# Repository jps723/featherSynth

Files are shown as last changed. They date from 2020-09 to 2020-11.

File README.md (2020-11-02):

# Feather Synth Build Notes 9/4/20

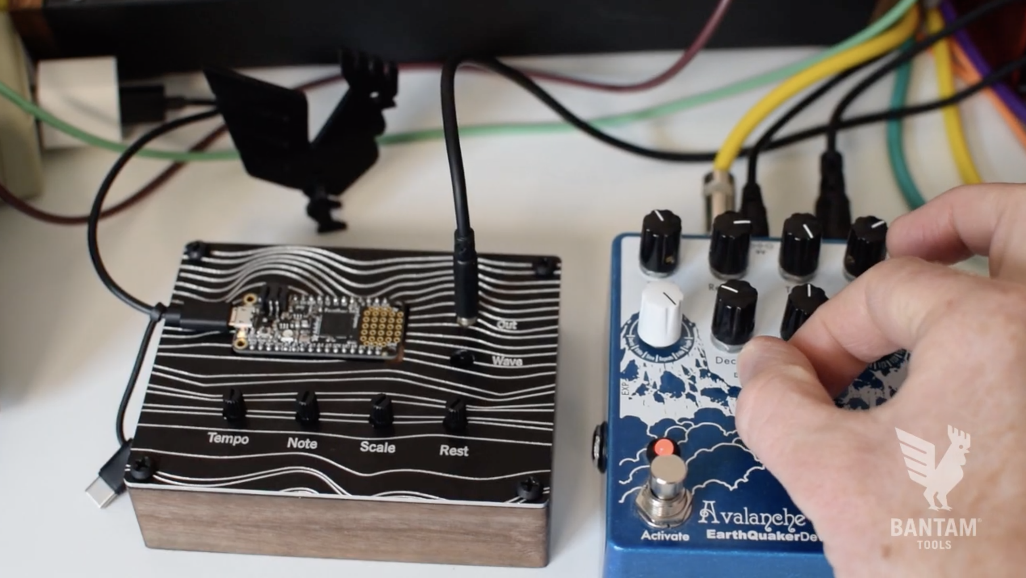
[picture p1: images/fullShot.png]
The Feather Synth sits on top of a table next to a guitar pedal. A hand is adjusting a knob on the pedal


A dual-oscillator polyphonic synthesizer project in collaboration with [Bantam Tools](https://www.bantamtools.com/).  The [project build](https://www.hackster.io/news/create-a-synth-and-sequencer-using-bantam-tools-desktop-cnc-milling-machine-83a0fdb942a3) guide is available on Hackster.

**Design Notes:**

The hardware component of this project is centered around the Adafruit Feather M4 Express.  This board has two 12bit DAC pins allowing for stereo audio synthesis, however this project does not use any stereo effects and delivers a mono signal to a 3.5mm mono audio jack.  

The hardware design has 5 inputs in the form of 4 potentiometers and a tactile button.  There are exposed female headers for an Adafruit Feather M4 Express.  The board will only fit in one direction, with the microUSB port facing to the left.  

If you look at the [pinout](https://learn.adafruit.com/adafruit-feather-m4-express-atsamd51/pinouts) of the M4 Express, you’ll see that we are using analog pin A0 as our DAC/audio output, and A2-A5 as our analog inputs.  Our button connects to digital pin 5.

The base software for the device uses these inputs to control an auto-advancing sequence of notes.  The knobs control the root note, the scale (it comes pre-programmed with the 7 diatonic modes), the probability that the note will play, and the time delay between notes/tempo.  Pressing the button will cycle through different waveforms/oscillator types.

**Synthesizer Design**
The synth is a polyphonic dual-oscillator synthesizer, each with independent bi-quad filters and envelopes.  The envelope settings are static while the filters are set to Low Pass Filters with the frequency cutoff randomly changing between two static values based on probability (math within the software -- this is unrelated to the probability knob).   

**Controls**
Root Note (Tonic)
The note from which the scale begins.  By default the notes to choose from range from A0 to C8

**Scale Selector**
There are a total of seven scales to choose from, beginning with the major scale, and then each mode variant resulting in the 7 diatonic modes in western music.

**Probability**
The probability that the note will be played, as calculated by comparing the knob’s position to a randomly generated number. Ex. 0-100% chance of playing

**Tempo**
The overall tempo of the sequence as determined by delay between each note

**Waveform Selector**
This is a series of oscillator combinations that get cycled through using the button.

## **Code**
The code is broken up into two separate files:  

**featherSynth.ino**
This is our primary code and is broken up into two sections: setup and loop.  Setup runs once, while loop cycles through continuously after the setup code has been executed. All of the code above the setup() function is required to call the library we are using (Audio.h), call our reference file (scales.h), and initialize our global variables. All of the code below the main loop() are functions that are called from either within setup() or loop().

Setup() contains code for setting audio memory allocation, pin assignment, and a function called oscillatorSetup() that is used for setting initial values of our oscillators/envelopes, etc.  These will mostly get overwritten by the loop however we want to define our instrument before the program begins to cycle.  

loop() contains the bulk of our code. We have a function called buttonHandler() that is used for managing what we want to happen when we press the button. If you find this function below, you can add further oscillator combinations.  Our potentiometer readings are assigned to the Feather pins here as well. If you want to change the order of the knobs, do it here.

The nested for() loop is used to populate the rootScaled array.  This determines what notes are in the sequence and the order that they’re arranged in.  There are two arrangements to choose from, either climbing the scale, or random selection.  Only one can be used at a time.

The frequency is calculated using a formula that stems from midi note values which are a standard form of notation for relating to frequency.

The frequency cutoff is currently assigned a 50% chance of being 7000 hz, or 2000 hz.  Experiment with these numbers.

The probabilityOfPlaying variable is compared to a random value between 0 and 100.  Since probabilityOfPlaying is also a value between 0 and 100, this is treated as a percentage.  You can experiment with these values.

playOsc1() and playOsc2() functions take one argument (frequency) which is calculated via the explanation above.  These functions also contain the methods for dictating the ADSR envelope values which are hardcoded and can be adjusted and should be experimented with.  The filter frequency cutoff and delayTime are also embedded in these functions, with delayTime being used to set the time between notes (our tempo).

The buttonHandler function counts the button presses and uses that count to cycle through the 7 different oscillator combinations in the switch statement.

scales.h
scales.h is a reference file where we have all of our different scales stored.  The base code has 7 scales (each of the diatonic modes) spread out across two octaves, with the root note at each octave playing at a 3:1 ratio to everything else.  This results in an 18 note array (an array with 18 indices), which are all a part of another array that contains each of these arrays (a total of 7).  If you were to add an 8th scale with 18 notes, then the scales[][] array should be initialized as scales[8][18].  This would also need to be changed in the .ino sketch in the rootScaled[][] array.  

Currently, if the knob is turned all the way to the left, the Ionian (major) Scale is selected.  As the knob is turned to the right, each scale from the array is played in the order that they are presented in the scales.h file.

## Build Process

**TOP**
Bit: 1/64”
Mill Time: ~3mins

**BOTTOM**
Bit: 1/32”, 1/64”
Mill Time: ~11mins

It’s easiest to solder in this order:
```
1. Vias
2. Resistor
3. Headers
4. Audio jack
5. Tactile button
6. Pots
```

Test

First follow [this guide](https://learn.adafruit.com/adafruit-feather-m4-express-atsamd51) for getting acquainted with the board and setting up your arduino IDE to use it. For the SAMD Board Support (Adafruit version), version 1.5.14 is verified to work.  Version 1.6+ has introduced a problem that will break the code without generating any errors.

Additionally, you will need to install the Adafruit fork of the PJRC Audio Library via the IDE.  



And also the following libraries:

```
Adafruit_SPIFlash
Adafruit_Zero_I2S_Library
SDFat-Adafruit Fork
```

Once all of the dependencies have been installed, and you’ve uploaded a trial sketch, upload the code that you’ve downloaded from the repository and have fun!  

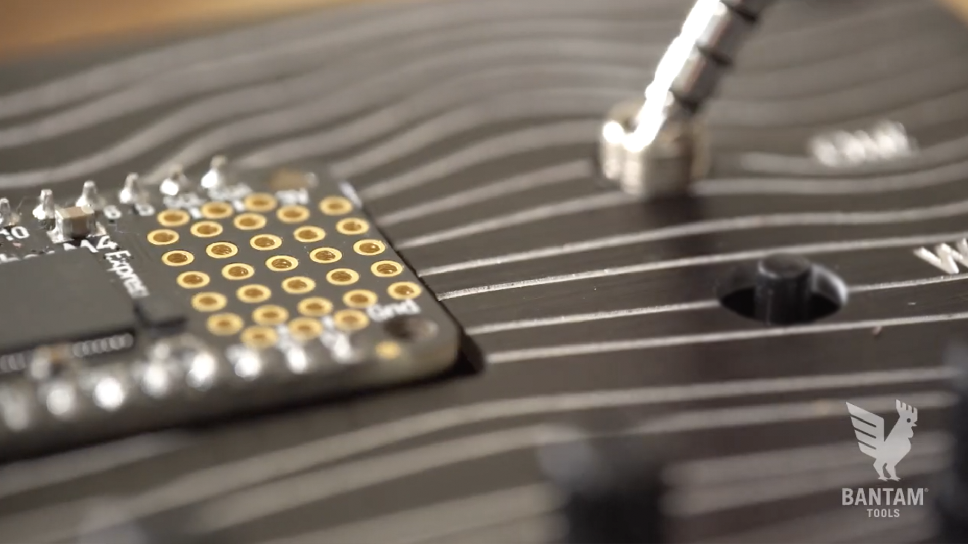
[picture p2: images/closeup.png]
A close up photo of a hand plugging in an audio cable into the 3.5mm audio jack on the Feather Synth


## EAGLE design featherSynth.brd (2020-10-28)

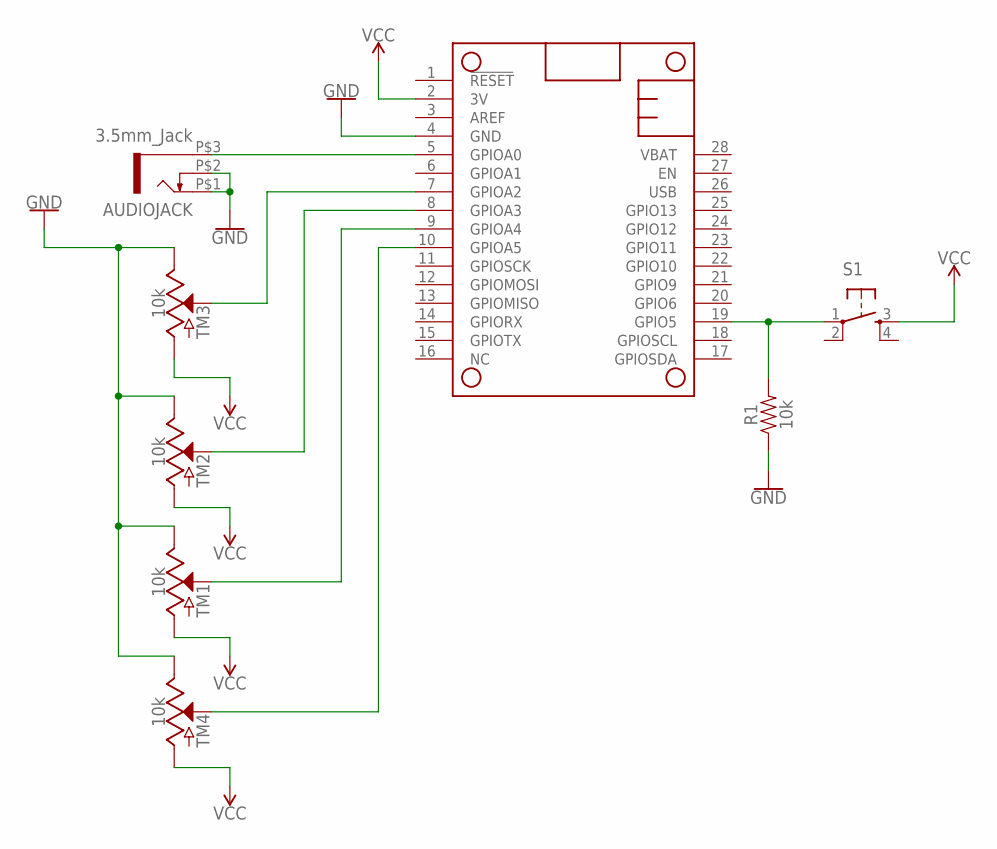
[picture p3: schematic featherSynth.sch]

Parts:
AUDIOJACK: 3.5mm_Jack; WQP-PJ301M-12_JACK
MS1: FEATHERWING
R1: 10k; AXIAL-0.3
S1: TAC_SWITCHPTH; TACTILE-PTH
TM1, TM2, TM3, TM4: 10k; POT-PTH-ALPS

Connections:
GND: AUDIOJACK.P$1 (2), AUDIOJACK.P$2 (3), MS1.4 (GND), R1.P$1 (1), TM1.P$1 (E), TM2.P$1 (E), TM3.P$1 (E), TM4.P$1 (E)
unnamed: AUDIOJACK.P$3 (1), MS1.5 (GPIOA0)
unnamed: MS1.8 (GPIOA3), TM2.P$2 (S)
unnamed: MS1.7 (GPIOA2), TM3.P$2 (S)
unnamed: MS1.9 (GPIOA4), TM1.P$2 (S)
unnamed: MS1.10 (GPIOA5), TM4.P$2 (S)
unnamed: MS1.19 (GPIO5), R1.P$2 (2), S1.1
VCC: MS1.2 (3V), S1.3, TM1.P$3 (A), TM2.P$3 (A), TM3.P$3 (A), TM4.P$3 (A)

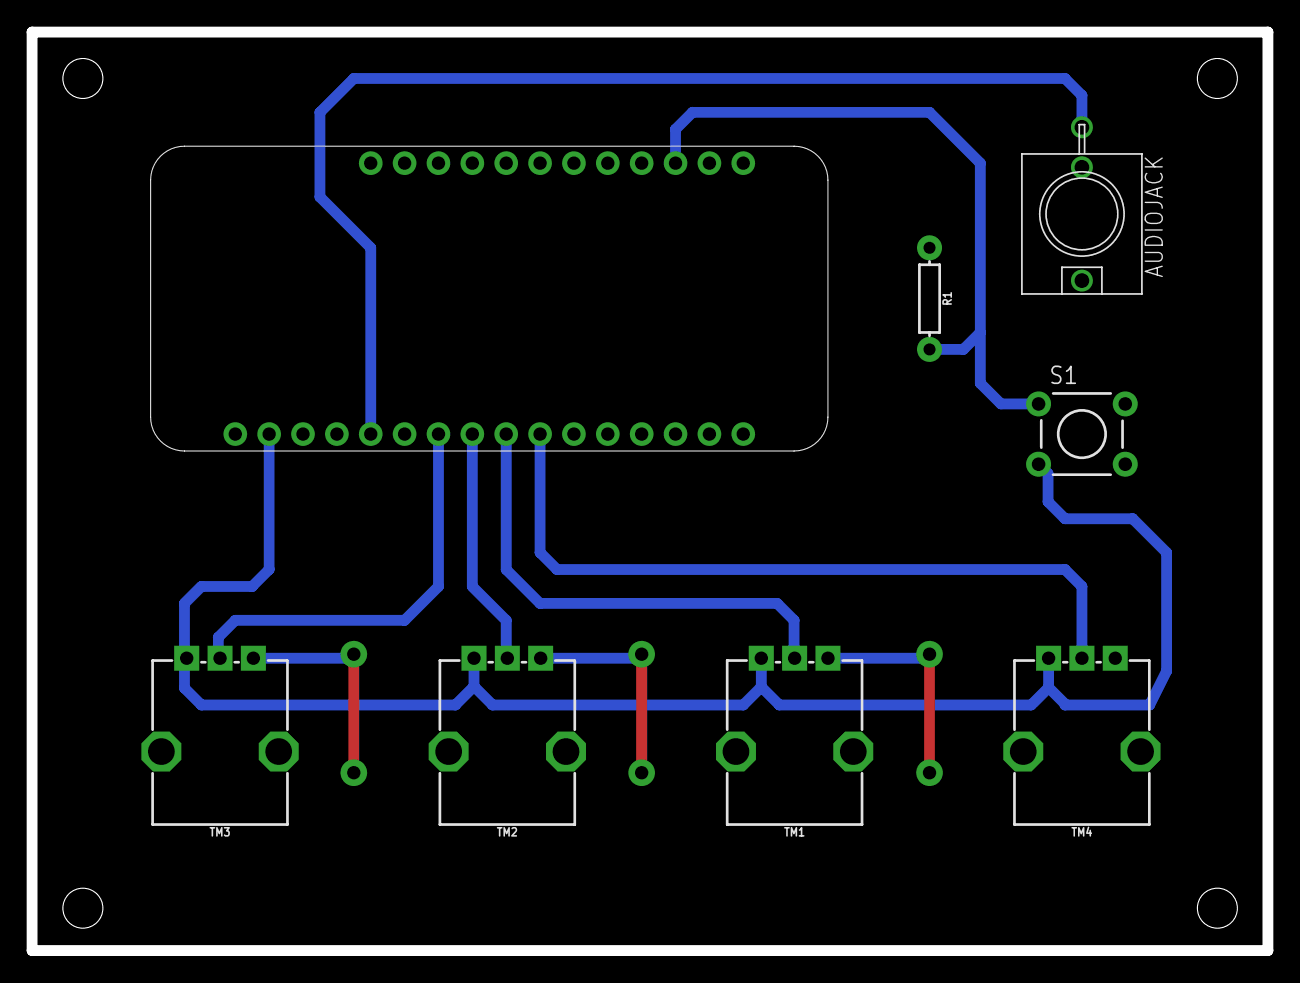
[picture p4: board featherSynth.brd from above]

Board: 2 copper layers, 92.7 x 68.9 mm, 8 parts (0 on the bottom side), 8 nets.

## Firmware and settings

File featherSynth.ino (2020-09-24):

/*
  This is a dual oscillator polyphonic synthesizer, each with
  independent filters and envelopes. The frequency of each
  oscillator is constrained to a key/scale based on user input.
  There are also user inputs for the the probability that the note
  will play, the tempo, and the oscillator types.

  This project was designed by Jesse Simpson in collaboration 
  with Bantam Tools.
  [PROJECT LINK]
*/

// Audio.h refers to the Adafruit fork of the PJRC Audio library.
// The forked version is required for use with the Adafruit 
// Feather M4 Express. 
#include <Audio.h>
#include "scales.h"

// middle A is the reference frequency for an
// equal-tempered scale. Set its frequency and note value.
// Thanks to Tom Igoe for this technique. Check out his
// Arduino sound examples at https://github.com/tigoe/SoundExamples.

#define NOTE_A4 69         // MIDI note value for middle A
#define FREQ_A4 440        // frequency for middle A

//a 2D array to store the notes of our scales in. 
//There are 7 scales, with 18 notes each
int rootScaled[7][18] = {};

int arpAdvanceCounter = 0;
//used for setting the tempo
int delayTime = 0;
//
int probabilityOfPlaying = 50;
// the cutoff frequency for our Low Pass Filters
int freqCutoff;
//the key we want our scale in
int rootNote = 60;

//for button handling
int buttonPin = 5;
int buttonPushCounter = 0;
int buttonState = 0;
int lastButtonState = 0;
float frequency;

//These are the synth definitions generated by the
//PJRC Audio System Design Tool: https://www.pjrc.com/teensy/gui/

// GUItool: begin automatically generated code
AudioSynthWaveform       waveform2;      //xy=109,246
AudioSynthWaveform       waveform1;      //xy=115,152
AudioFilterBiquad        biquad2;        //xy=255,245
AudioFilterBiquad        biquad1;        //xy=256,152
AudioEffectEnvelope      envelope2;      //xy=421,249
AudioEffectEnvelope      envelope1;      //xy=444,153
AudioMixer4              mixer1;         //xy=571,246
AudioOutputAnalogStereo  Audio_Output;          //xy=774,156
AudioConnection          patchCord1(waveform2, biquad2);
AudioConnection          patchCord2(waveform1, biquad1);
AudioConnection          patchCord3(biquad2, envelope2);
AudioConnection          patchCord4(biquad1, envelope1);
AudioConnection          patchCord5(envelope2, 0, mixer1, 1);
AudioConnection          patchCord6(envelope1, 0, mixer1, 0);
AudioConnection          patchCord7(mixer1, 0, Audio_Output, 0);
// GUItool: end automatically generated code

void setup() {
  //Set default audio memory
  AudioMemory(10);
  // Initialize processor and memory measurements
  AudioProcessorUsageMaxReset();
  AudioMemoryUsageMaxReset();
  //begin serial communication
  Serial.begin(115200);
  pinMode(buttonPin, INPUT);
  //default settings for both oscillators
  oscillatorSetup();
  delay(500);
}


void loop() {
  //A function for button handling to change the instrument
  buttonHandler();
  //read our input sensors and store them in variables
  int bpmReading = analogRead(A2);
  int rootReading = analogRead(A3);
  int scaleReading = analogRead(A4);
  int probabilityReading = analogRead(A5);
  

  //result is the BPM we want in 4:4 (quarter notes)
  int masterTempo = map(bpmReading, 0, 1023, 60, 800);

  //Divide 60,000 (ms) by the desired BPM to get the duration of a single beat – a quarter note.
  //Quarter note duration = 60,000 / bpm = x ms.
  //example: Time between beats = 60,000/100 = 600ms
  delayTime = 60000 / masterTempo;

  // convert sensor reading to 21 - 108 range
  // which is the range of MIDI notes on an 88-key keyboard
  // (from A0 to C8):
  int rootNote = map(rootReading, 0, 1023, 21, 108);


  //map the scaleReading to the length of the array
  int scaleArrayPosition = map(scaleReading, 0, 1023, 0, scalesArrayLength - 1); // can also use scalesArrayLength

  //map the probability knob reading from 0-100 so that we can think about it in terms of %
  probabilityOfPlaying = map(probabilityReading, 0, 1023, 0, 100); // can also use diatonicArrayLength

  //populate the rootScaled array with all of the notes based on our chosen scale and root note
  for (int i = 0; i < scalesArrayLength; i++) {
    for (int j = 0; j < diatonicArrayLength; j++) {
      //climb up the scale
      //rootScaled[i][j] = rootNote + (scales[scaleArrayPosition][arpAdvanceCounter]);
      //randomize the note order
      rootScaled[i][j] = rootNote + (scales[scaleArrayPosition][random(arpAdvanceCounter)]);
    }
  }

  //read the position of the knob, pull the associated MIDI value from the array, and then convert it to a frequency
  frequency =  FREQ_A4 * pow(2, ((rootScaled[scaleArrayPosition][arpAdvanceCounter] - NOTE_A4) / 12.0));

  //randomly assign a frequency cutoff for the Low Pass Filter
  int r = random(100);
  if (r > 50) {
    freqCutoff = 7000;
  } else {
    freqCutoff = 2000;
  }

  //Calculate a random number
  int ranNum = random(100);
  //compare that number to the value of the probability knob
  if (ranNum <= probabilityOfPlaying) {
    arpAdvanceCounter++;
    if (arpAdvanceCounter >= diatonicArrayLength) {
      arpAdvanceCounter = 0;
    }
    playOsc1(frequency);
    playOsc2(frequency);
    waveform1.amplitude(.5);
    waveform2.amplitude(.5);
  } else {
    arpAdvanceCounter++;
    if (arpAdvanceCounter >= diatonicArrayLength) {
      arpAdvanceCounter = 0;
    }
    playOsc1(0);
    playOsc2(0);
    waveform1.amplitude(0);
    waveform2.amplitude(0);
  }

}

int playOsc1(int freq) {
  waveform1.frequency(freq);
  envelope1.noteOn();
  envelope1.attack(5);
  envelope1.hold(0);
  envelope1.decay(1000);
  envelope1.sustain(.5);
  biquad1.setLowpass(1, freqCutoff, 0.71);
  envelope1.noteOff();
  delay(delayTime);
}

int playOsc2(int freq) {
  //play oscillator2 at half of the indicated frequency (1 octave down)
  waveform2.frequency(freq / 2);
  envelope2.noteOn();
  envelope2.attack(5);
  envelope2.hold(0);
  envelope2.decay(1000);
  envelope2.sustain(.5);
  biquad2.setLowpass(0, freqCutoff, 0.71);
  envelope2.noteOff();
  delay(delayTime);

}

void buttonHandler() {
  // read the pushbutton input pin:
  buttonState = digitalRead(buttonPin);
  if (buttonState != lastButtonState) {
    // if the state has changed, increment the counter
    if (buttonState == HIGH) {
      // if the current state is HIGH then the button went from off to on:
      buttonPushCounter++;
    } else {
      //if the button isn't pressed, don't do anything
    }
    delay(60);
  }
  lastButtonState = buttonState;

  switch (buttonPushCounter) {
    case 0:
      waveform1.begin(WAVEFORM_SINE);
      waveform2.begin(WAVEFORM_SINE);
      break;
    case 1:
      waveform1.begin(WAVEFORM_TRIANGLE);
      waveform2.begin(WAVEFORM_TRIANGLE);
      break;
    case 2:
      waveform1.begin(WAVEFORM_SAWTOOTH);
      waveform2.begin(WAVEFORM_SAWTOOTH);
      break;
    case 3:
      waveform1.begin(WAVEFORM_TRIANGLE);
      waveform2.begin(WAVEFORM_SAWTOOTH);
      break;
    case 4:
      waveform1.begin(WAVEFORM_SAWTOOTH_REVERSE);
      waveform2.begin(WAVEFORM_SAWTOOTH_REVERSE);
      break;
    case 5:
      waveform1.begin(WAVEFORM_SQUARE);
      waveform2.begin(WAVEFORM_SQUARE);
      break;
    case 6:
      waveform1.begin(WAVEFORM_SINE);
      waveform2.begin(WAVEFORM_SQUARE);
      break;
  }
  if (buttonPushCounter > 6) {
    buttonPushCounter = 0;
  }
}

void oscillatorSetup() {
  //Default settings for oscillator 1
  waveform1.begin(WAVEFORM_TRIANGLE);
  //Default envelope1
  envelope1.attack(5);
  envelope1.hold(0);
  envelope1.decay(1);
  envelope1.sustain(.5);
  //default filter1 set to lowpass
  biquad1.setLowpass(0, 14000, .71);
  waveform1.pulseWidth(.85);

  //Default settings for oscillator 2
  waveform2.begin(WAVEFORM_SAWTOOTH);
  //Default envelope2
  envelope2.attack(5);
  envelope2.hold(0);
  envelope2.decay(1);
  envelope2.sustain(.5);
  //default filter2 set to lowpass
  biquad2.setLowpass(0, 14000, .71);
  waveform2.pulseWidth(.45);

}

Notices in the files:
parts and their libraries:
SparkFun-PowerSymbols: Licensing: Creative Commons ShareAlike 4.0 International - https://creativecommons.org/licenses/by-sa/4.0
